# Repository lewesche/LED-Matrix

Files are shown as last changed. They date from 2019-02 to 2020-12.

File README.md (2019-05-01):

# LED-Matrix

## https://www.youtube.com/watch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

The LED Matrix is a arduino driven 8x8 array of lights with an integrated microphone that hangs up on the wall. I designed the matrix as a fun little test bed for music visualization software, and it came out pretty cool so I thought I'd share. It costs about $40 for all the parts that go into one of these. 

## Electrical Hardware

I designed an 8 inch square PCB with spots for an arduino nano, microphone, DC jack, 64 LEDs, and a button. I've included a full BOM and gerber file for the PCB, which can easily be uploaded to any PCB manufacturers site. 

This thing requires a bit of home assembly for sure. The LED's are surface mount components, but they really aren't too hard to solder at home with some practice and a nice pointy iron. I didn't use any solder paste or anything special. Make sure you pay attention to the orientation of the LED's, arduino, and microphone! I included some seperate sketches that can be uploaded to the arduino to test the red, green, and blue channels of each LED during assembly. 

Note: The LED spec sheet calls for a capacitor connection between the ground and 5v input of each LED, but I ommited this for simplicity. So far I haven't noticed any issues with this, I suspect this is just to enable the LED's to change color at a ridiculously high framerate. 

## 3D Printed Hardware

Three parts make up the structure of the Matrix, and they are all easy to 3D print. The housing is just a bit larger than a 8 inch square. On my printer it takes about a full day of printing to make one of these. No screws or hardware are required. 

The printed parts include a housing that the other parts slide into, a set of dividers to seperate the light coming from each LED, and a top to seal it off. I would suggest printing with black PLA, since dark colors do a good job of keeping light from bleeding through cells. If a soldered connection or LED ever fails, its super easy to remove and work on the PCB. The only passive hardware not 3D printed is the 8 inch square black accrylic screen, which is a pretty easy thing to find for a couple bucks. 

Asembely Pics: https://drive.google.com/open?id=1HWLcNDVe-Ao-Pyr7k9aOO6FC9LVxDk2P

## Software

I set up a simple software framework for controlling LED's and measuring audio input. The arduino runs in "freeflow mode", which lets the audio sample at around 10khz and measure frequencies up to 5khz. This could be tweaked to run faster, but I figured that 5khz was probably a reasonable top range. The cheap mic I used seems to have some trouble picking up low end sounds too. I omited the lowest frequency bin from the animation since they were much noisier and less responsive than the others, so the device is less sensitive to low end heavy sounds like a kick. 

### Dependencies

I used two awesome libraries for the project:

http://fastled.io/ - the ubiquitous FastLED

http://wiki.openmusiclabs.com/wiki/ArduinoFHT - Awesome FHT implementation by OpenMusicLabs

## Animations

### Frequency Spectrum Analzyer

This is most built out animation so far. It displays a colorful frequency spectrum with lows on the left and highs on the right. The spectrum and background colors change over time, or when the signal dies down.  

### Pop
This simple animation creates a coloful pop when a sound threshold is reached.

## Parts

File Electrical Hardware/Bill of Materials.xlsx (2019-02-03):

ID | Item | Model | Qty per Matrix |  | Price | Link
1 | LEDs | WS2812B-B | 64 |  | 13.42 | https://www.ebay.com/itm/200PC-WS2812B-Built-in-5050-RGB-LED-SMD-Chip-Light-Individual-Addressable/372029003468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
2 | Arduino Nano | CH340 chipset Nano | 1 | ~ | 5
3 | Microphone | MAX 9814 clone | 1 |  | 2 | https://www.ebay.com/itm/MAX9814-Microphone-AGC-Amplifier-Board-Module-Auto-Gain-Control-CMA-4544PF-W-new/262450402787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
4 | Button | 6 x 6 x 9mm | 1 |  | 2 | https://www.ebay.com/itm/10pcs-6x6x9mm-Right-Angle-Tactile-Tact-Push-Button-Micro-Switch-Momentary/162041570018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
5 | DC Jack | 2.1mm barrel | 1 |  | 1 | https://www.ebay.com/itm/10pcs-DC-Power-Jack-Socket-2-1mm-Barrel-Type-PCB-Mount-M2L4/253379152191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
6 | Power Supply | 5V, 3A min, best 4A | 1 |  | 12 | https://www.ebay.com/itm/5V-1A-2A-3-4A-5A-DC-Power-Supply-Charger-Adapter-ID-OD-2-5mm-x-5-5mm-Center-PSU/351139392368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
7 | PCB | ~~~ | 1 | ~ | 8 | See Electrical Hardware folder for Gerber Files
 | Total |  |  |  | 35.42

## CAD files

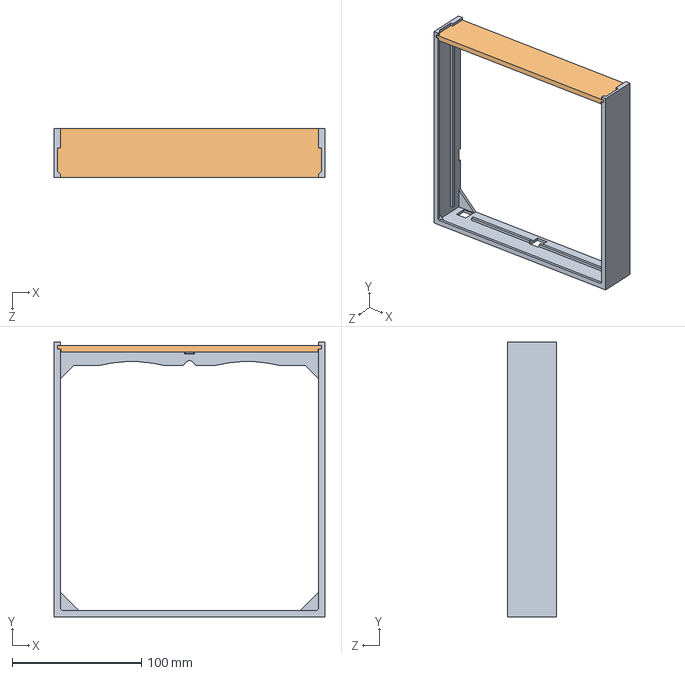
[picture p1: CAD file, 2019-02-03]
3D Printed Hardware/Matrix_Assem_V2.SLDASM
209.5 x 212.5 x 38.1 mm
Sides
Top

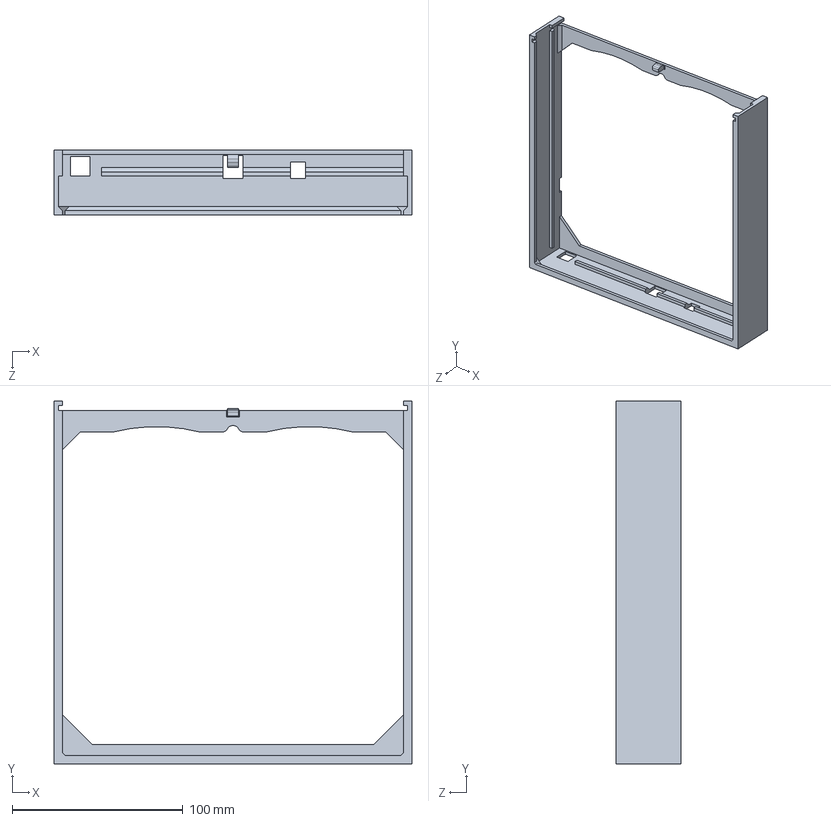
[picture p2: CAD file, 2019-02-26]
3D Printed Hardware/Sides.SLDPRT
209.5 x 212.5 x 38.1 mm

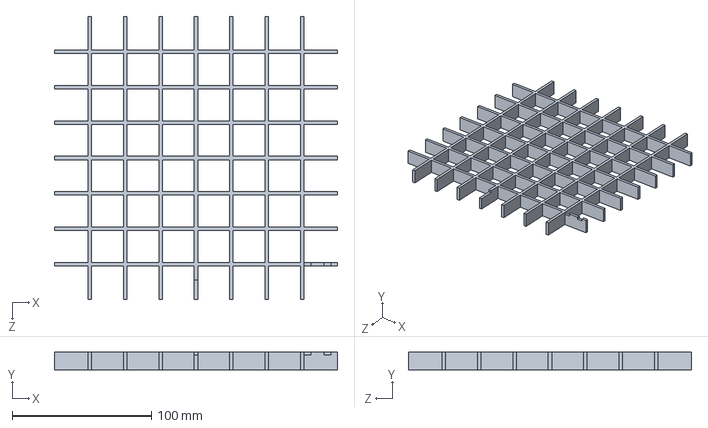
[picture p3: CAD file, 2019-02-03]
3D Printed Hardware/Dividers.SLDPRT
203.2 x 12.7 x 203.2 mm

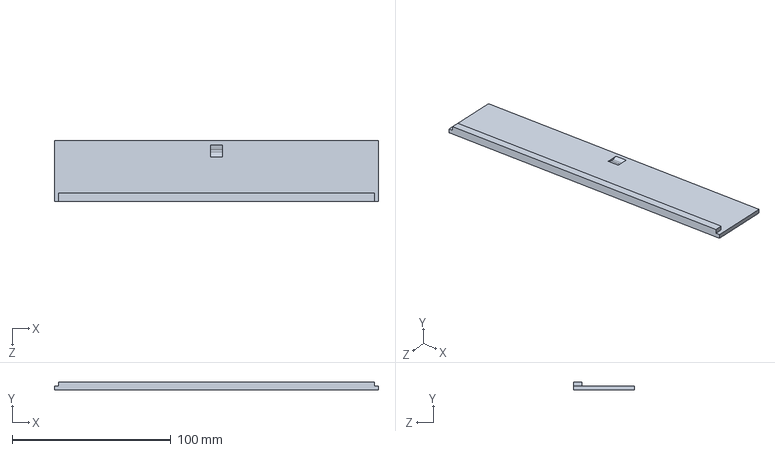
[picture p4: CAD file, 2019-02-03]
3D Printed Hardware/Top.SLDPRT
203.8 x 5.08 x 38.1 mm

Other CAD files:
3D Printed Hardware/Dividers.STL
3D Printed Hardware/Sides.STL
3D Printed Hardware/Top.STL

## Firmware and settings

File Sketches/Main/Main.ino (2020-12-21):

#include <Arduino.h>
#include "FrequencySpectrum.h"
#include "Pop.h" 
//#include "Slide.h"
#include "Matrix.h"

//Create a pointer to a matrix base class
Matrix* matrix;

void setup() 
{   
  Serial.begin(9600);
  randomSeed(analogRead(2));
}


void loop() 
{
  while(true)
  {
    matrix = new FrequencySpectrum;
    matrix->m_run();
    delete matrix;
  
    matrix = new Pop;
    matrix->m_run();
  
    matrix->m_off();
    delete matrix;
  }
}

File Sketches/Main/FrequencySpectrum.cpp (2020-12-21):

#include <Arduino.h>
#include "FrequencySpectrum.h"

#define GRID_SIZE 8

void FrequencySpectrum::m_intro(int fadeTime)
{
  int percentBrightness = 0;
  m_fillSolidColor(m_backgroundColor);

  unsigned long setTime = millis();
  unsigned long t = 0;
  
  while(true)
  {
    for(int y = GRID_SIZE-1; y >= 0; --y)
    {
      percentBrightness = pow(static_cast<double>(t)/fadeTime, 4) * (50*(y+1))/(GRID_SIZE);
      for(int x = 0; x < GRID_SIZE; ++x)
      {
        setPercentBrightness(x, y, percentBrightness);
      }
    } 
    FastLED.show();
    t = millis() - setTime; 
    if (t > fadeTime)
      return;
  }
}

void FrequencySpectrum::m_newSpectrumColors()
{
  
  for(int i = 0; i < 2; ++i)
  {
    m_lastPeakEndColors[i] = getRandomColor();
    m_nextPeakEndColors[i] = getRandomColor();
  }

    m_peakColors[0] = m_lastPeakEndColors[0];
    m_peakColors[GRID_SIZE-1] = m_lastPeakEndColors[1];

  // Fill in interior colors
  for(int i = 1; i < GRID_SIZE-1; ++i)
  {
    for(int c = 0; c < 3; ++c)
    {
      m_peakColors[i].val[c] = (m_peakColors[0].val[c] * (GRID_SIZE-1-i) + m_peakColors[GRID_SIZE-1].val[c] * i) / 7;
    }
  }   
  m_peakStepCount = 0;
}


void FrequencySpectrum::m_drawBackground()
{
  int percentBrightness = 0;
  int percentFade = 0;
  
  if((millis()-m_backgroundStepTime) > m_backgroundPeriod/m_backgroundSteps)
  {
    m_backgroundStepTime = millis();  
    for(int c = 0; c < 3; ++c)
      m_backgroundColor.val[c] = (m_lastBackgroundColor.val[c]*(m_backgroundSteps-m_backgroundStepCount) + m_nextBackgroundColor.val[c]*m_backgroundStepCount)/m_backgroundSteps;

    for(int y = 0; y < GRID_SIZE; ++y)
    {
      percentBrightness = (50*(y+1))/(GRID_SIZE);
      for(int x = 0; x < GRID_SIZE; ++x)
      {
        m_leds[cvtCoords(x, y)].setRGB(
          (m_backgroundColor.val[0]*percentBrightness)/100,
          (m_backgroundColor.val[1]*percentBrightness)/100, 
          (m_backgroundColor.val[2]*percentBrightness)/100);
        for(int c = 0; c < 3; ++c)
          m_backgroundMatrix[x][y].val[c] = (m_backgroundColor.val[c]*percentBrightness)/100;
      }
    }
    m_backgroundStepCount+=1;
  }

  
  if(m_backgroundStepCount > m_backgroundSteps)
  {
    m_lastBackgroundColor = m_nextBackgroundColor;
    m_nextBackgroundColor = getRandomColor();
    m_backgroundStepCount = 0;
  }
}

void FrequencySpectrum::m_drawNewPeak(int x)
{
  m_peaks[x] = m_soundLevels[x];
  m_setTime[x] = millis();
  for (int y = 0; y <= m_peaks[x]; ++y)
  {
    m_matrix[x][y] = m_peakColors[x];
    setPercentBrightness(x, y, 100);
  }
}

void FrequencySpectrum::m_fadePeak(int x)
{  
  
  //Draw new peaks, drop existing peaks
  for (int y = 0; y < m_peaks[x]; ++y)
  {
    m_matrix[x][y] = m_peakColors[x];
    setPercentBrightness(x, y, 100);
  }
  
  int percentBrightness = 100 - static_cast<int>((100 * (millis() - m_setTime[x]))/m_decayTime);
  if (percentBrightness > 0)
  {  
    m_interpColors(x, m_peaks[x], m_peakColors[x], m_backgroundMatrix[x][m_peaks[x]], percentBrightness);
  }
  else
  {
    m_interpColors(x, m_peaks[x], m_peakColors[x], m_backgroundMatrix[x][m_peaks[x]], 0);     //Fill in pixel with background color
    m_peaks[x]--;                                                                       //Peak height = -1 once lowest pixel fades                                          
    m_setTime[x] = millis();                                                            //Reset duration counter for fading purposes
    if(m_peaks[x] >= 0)                                                  
      setPercentBrightness(x, m_peaks[x], 100);                                         //If the new peak is greater than -1, aka exists, set it's brightness to 100
  }
} 

void FrequencySpectrum::m_transitionPeakColors()
{
  //Serial.println(m_peakCycleTime);
  if(m_peakCycleTime > 2*m_peakPeriod)
  {
    m_transitioning = true;
    //Cycle end colors
    if((millis()-m_peakStepTime) > m_peakPeriod/m_peakSteps)
    {
      m_peakStepTime = millis();
      for(int c = 0; c < 3; ++c)
      {
        m_peakColors[0].val[c] = (m_lastPeakEndColors[0].val[c]*(m_peakSteps-m_peakStepCount) + m_nextPeakEndColors[0].val[c]*m_peakStepCount)/m_peakSteps;
        m_peakColors[GRID_SIZE-1].val[c] = (m_lastPeakEndColors[1].val[c]*(m_peakSteps-m_peakStepCount) + m_nextPeakEndColors[1].val[c]*m_peakStepCount)/m_peakSteps;
      }
      m_peakStepCount++;
      //Serial.println(m_peakStepCount);
    }
  
    // Fill in interior colors
    for(int i = 1; i < GRID_SIZE-1; ++i)
    {
      for(int c = 0; c < 3; ++c)
      {
        //Serial.println("b6");
        m_peakColors[i].val[c] = (m_peakColors[0].val[c] * (GRID_SIZE-1-i) + m_peakColors[GRID_SIZE-1].val[c] * i) / 7;
      }
    }
    
    if(m_peakStepCount > m_peakSteps)
    {
      m_lastPeakEndColors[0] = m_nextPeakEndColors[0];
      m_lastPeakEndColors[1] = m_nextPeakEndColors[1];
      m_nextPeakEndColors[0] = getRandomColor();
      m_nextPeakEndColors[1] = getRandomColor();
      m_peakStepCount = 0;
      m_peakCycleTime = 0;
      m_transitioning = false;
    }
  }
 
  m_peakCycleTime += 10;

  return;
}

void FrequencySpectrum::m_outro(int fadeTime)
{
  int percentBrightness;
  unsigned long setTime = millis();
  unsigned long t = 0;

  m_fillSolidColor(m_backgroundColor);
  
  while(true)
  {
    for(int y = GRID_SIZE-1; y >= 0; --y)
    {
      percentBrightness = pow((fadeTime-static_cast<double>(t))/fadeTime, 4) * (50*(y+1))/(GRID_SIZE);
      for(int x = 0; x < GRID_SIZE; ++x)
      {
        setPercentBrightness(x, y, percentBrightness);
      }
    } 
    FastLED.show();
    t = millis() - setTime; 
    
    if (t > fadeTime)
    {
      m_clear();
      return;
    }
  }
}

void FrequencySpectrum::m_sleep()
{
  while(true)
  {
    m_FHT();
    if(m_soundLevelSum > 8)
      return;
  }
}
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

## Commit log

2019-02-03 Initial Commit
    The hardware is pretty squared away. Sound detecting works pretty well and animation is fast and smooth. So far I've only come up with 1 audio reactive effect, but I've got plans for a couple more.
    [Bill of Materials.xlsx, Dividers.SLDPRT, Dividers.STL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]
2019-02-15 Added "sleep" timer, outro function
    also added random function seeding
2019-02-26 Changes to case to fit button
    [Sides.SLDPRT, Sides.STL]
2019-03-09 Integrated button, new effect prototype, hardware updates
    The button cycles through effects, including an "off" mode
2019-03-10 Fixed a bug that was preventing the programs from cycling properly via the button
    [FrequencySpectrum.cpp, Main.ino, Matrix.cpp]
2020-12-21 pretty dramatic performance fixes
    [FrequencySpectrum.cpp, FrequencySpectrum.h, Main.ino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]
